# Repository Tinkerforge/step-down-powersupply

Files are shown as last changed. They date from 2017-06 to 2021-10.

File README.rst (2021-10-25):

Step-Down Power Supply
======================

This repository contains the hardware design files for the Step-Down
Power Supply.

Repository Content
------------------

hardware/:
 * Contains kicad project files and additionally schematics as pdf

Hardware
--------

The hardware is designed with the open source EDA Suite KiCad
(http://www.kicad.org). Before you are able to open the files,
you have to install the Tinkerforge kicad-libraries
(https://github.com/Tinkerforge/kicad-libraries). You can either clone
them directly in hardware/ or clone them in a separate folder and
symlink them into hardware/
(ln -s kicad_path/kicad-libraries project_path/hardware). After that you
can open the .pro file in hardware/ with kicad and from there view and
modify the schematics and the PCB layout.

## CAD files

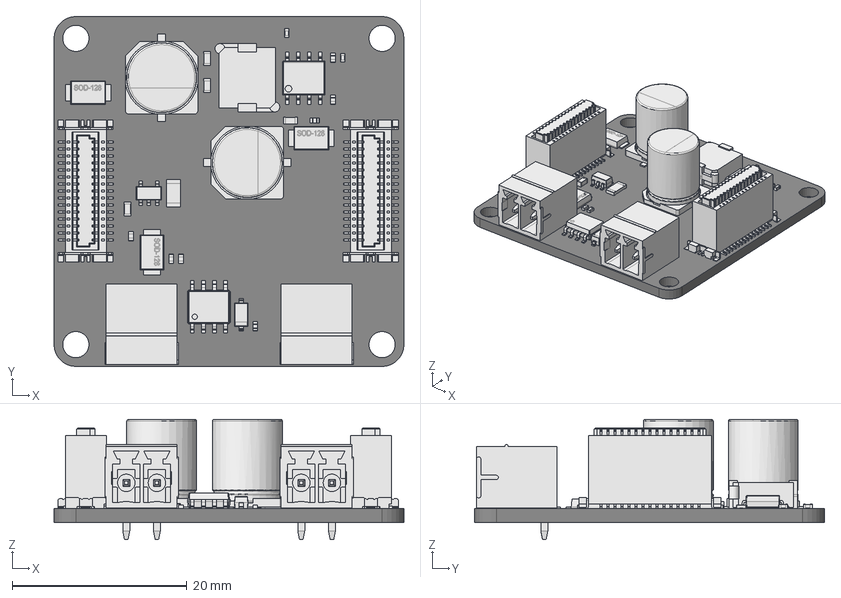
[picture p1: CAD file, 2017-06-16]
hardware/step-down.FCStd
40.0 x 40.0 x 13.8 mm
Pcb
ASSEMBLY_
C_0603_
C_0402_
C_0402_001
C_0603_001
C_0603_002
ASSEMBLY_001
SOD-123_
SOD-128_
SOD-128_001
SOD-128_002
C_0603_003
88021-12XX_
88021-12XX_001
2er_Phoenix_Buchse_Schwarz_
2er_Phoenix_Buchse_Grün_
soic_8_39x49_p127_
R_0402_
R_0402_001
R_0402_002
R_1206_
R_0402_003
R_0402_004
R_0402_005
R_0402_006
SOT-23-5_
SO-8_

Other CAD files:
hardware/V1.3/step_down.FCStd

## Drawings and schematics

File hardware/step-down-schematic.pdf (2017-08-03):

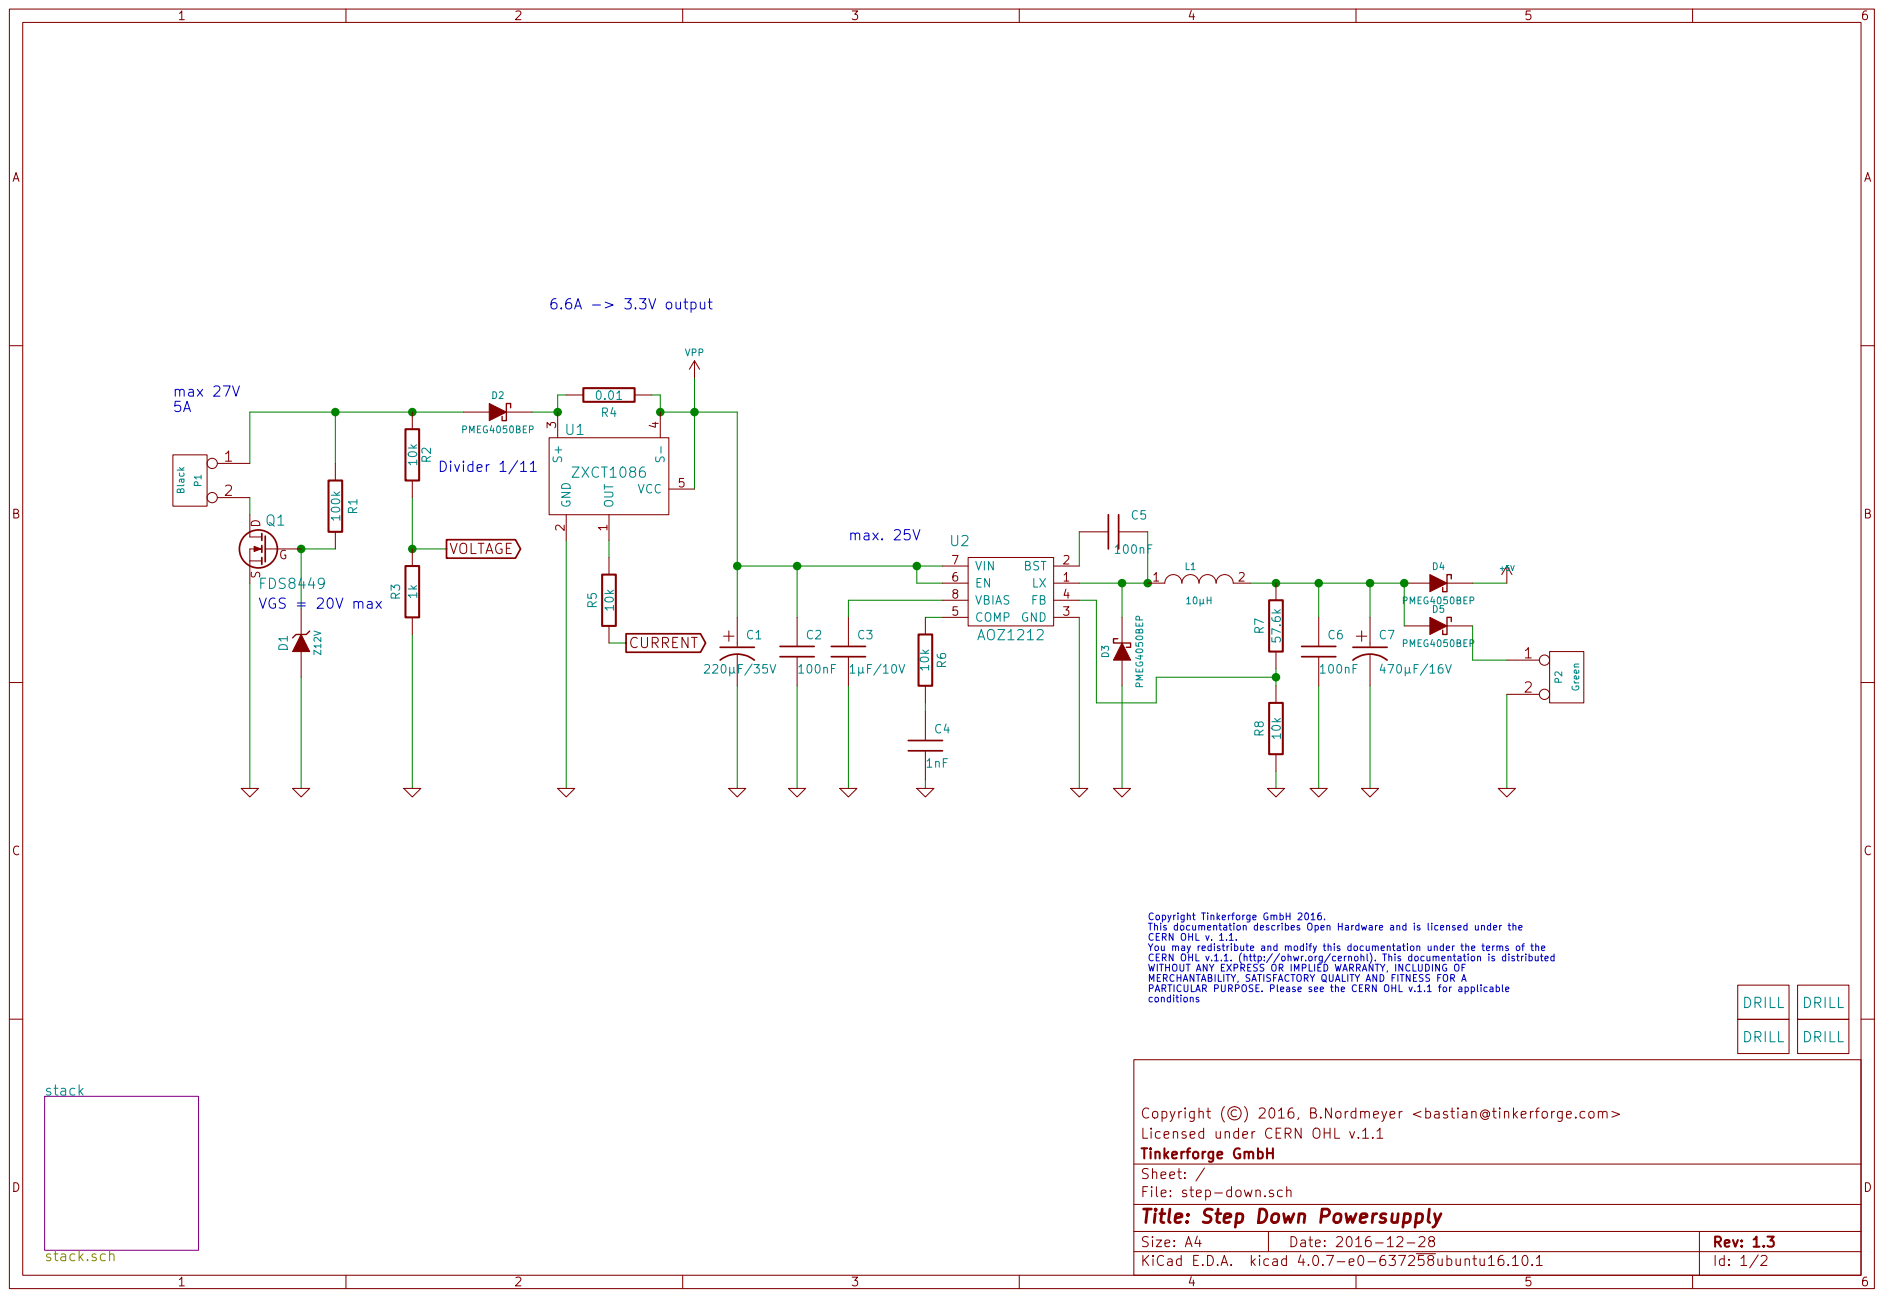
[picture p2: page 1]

PARTICULAR PURPOSE. Please see the CERN OHL v.1.1 for applicable
conditions

Licensed under CERN OHL v.1.1 Copyright (©) 2016, B.Nordmeyer <bastian@tinkerforge.com>

File: step-down.sch Sheet: / Tinkerforge GmbH

Id: 1/2 Title: Step Down Powersupply

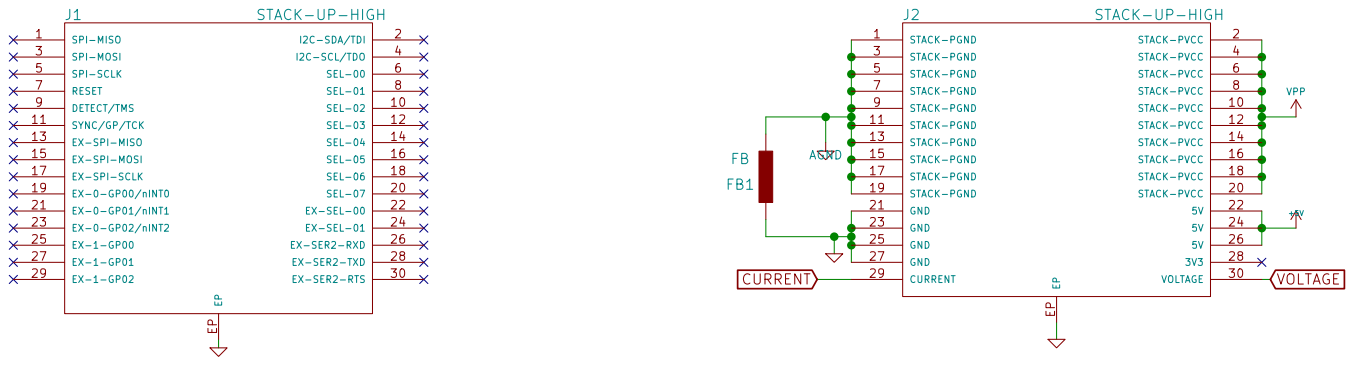
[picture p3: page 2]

Licensed under CERN OHL v.1.1 Copyright (©) 2016, B.Nordmeyer <bastian@tinkerforge.com> FB1 FB

File: stack.sch Sheet: /stack/ Tinkerforge GmbH

Id: 2/2 Title: Step Down Powersupply

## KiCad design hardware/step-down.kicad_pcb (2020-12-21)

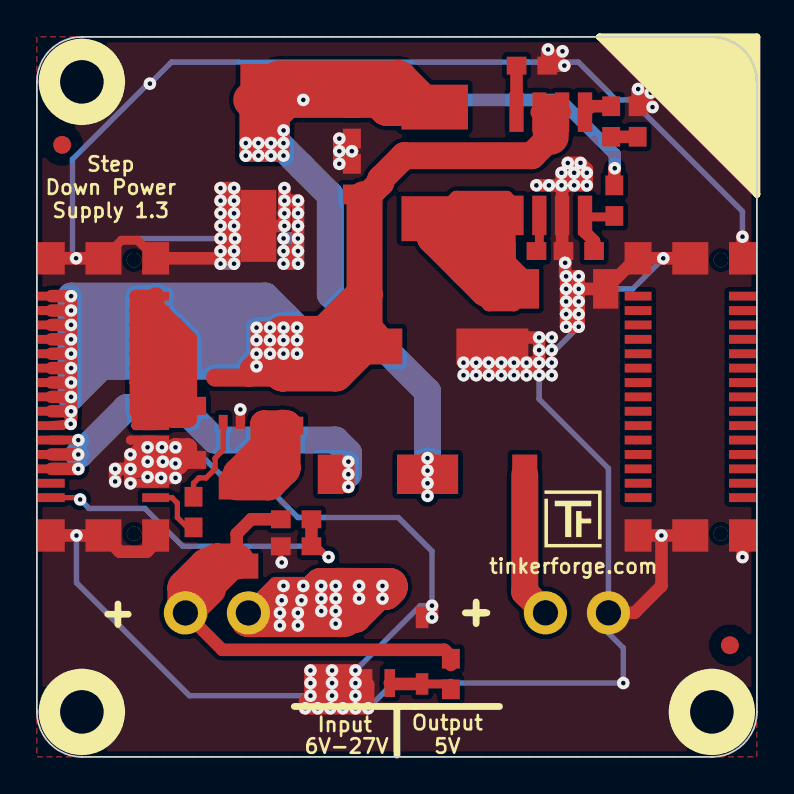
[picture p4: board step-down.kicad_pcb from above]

Board: 2 copper layers, 40.0 x 40.0 mm, 38 parts (0 on the bottom side), 19 nets.

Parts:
C1: 220µF/35V; ELKO_83
C2, C5, C6: 100nF; C0603E
C3: 1µF/10V; C0603E
C4: 1nF; C0603E
C7: 470µF/16V; ELKO_83
D1: Z12V; SOD-123
D2, D3, D4, D5: PMEG4050BEP; SOD-128
FB1: FB; R1206
Fiducial_Mark: VAL**; Fiducial_Mark
Fiducial_Mark#2: VAL**; Fiducial_Mark
J1, J2: STACK-UP-HIGH; BTB08-ACS-TOP
L1: 10µH; SRP7030
P1: Black; OQ_2P
P2: Green; OQ_2P
Q1: FDS8449; SOIC-8-MOSFET
R1: 100k; R0603E
R2, R5: 10k; R0603E
R3: 1k; R0603E
R4: 0.01; R1206
R6, R8: 10k; C0603E
R7: 57.6k; C0603E
Ref**: Val**
U1: ZXCT1086; SOT23-5
U2: AOZ1212; SO-8
U3, U4, U5, U6: DRILL; DRILL_NP
VAL: WEEE_7mm
VAL#2: CE_5mm

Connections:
+5V: D4.2, J2.22, J2.24, J2.26
AGND: FB1.2, J2.1, J2.3, J2.5, J2.7, J2.9, J2.11, J2.13, J2.15, J2.17, J2.19
CURRENT: J2.29, R5.2
GND: C1.2, C2.2, C3.2, C4.2, C6.2, C7.2, D1.1, D3.1, FB1.1, J1.EP, J2.21, J2.23, J2.25, J2.27, J2.EP, P2.2, Q1.S, R3.2, R8.2, U1.2, U2.3
unnamed: C3.1, U2.8
unnamed: C4.1, R6.1
unnamed: C5.1, D3.2, L1.1, U2.1
unnamed: C5.2, U2.2
unnamed: C6.1, C7.1, D4.1, D5.1, L1.2, R7.1
unnamed: D1.2, Q1.G, R1.2
unnamed: D2.1, P1.1, R1.1, R2.1
unnamed: D2.2, R4.2, U1.3
unnamed: D5.2, P2.1
unnamed: P1.2, Q1.D
unnamed: R5.1, U1.1
unnamed: R6.2, U2.5
unnamed: R7.2, R8.1, U2.4
VOLTAGE: J2.30, R2.2, R3.1
VPP: C1.1, C2.1, J2.2, J2.4, J2.6, J2.8, J2.10, J2.12, J2.14, J2.16, J2.18, J2.20, R4.1, U1.4, U1.5, U2.6, U2.7

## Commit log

2013-12-02 add hardware files of version 1.2
    [stack.sch, step-down.brd, step-down.kicad_pcb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]
2013-12-02 schematic in color fix input voltage hint
    [stack.sch, step-down.sch]
2015-05-07 start new prototype of step down power supply with filtered inputs, fuse and diode protected output
    [stack.sch, step-down.kicad_pcb, step-down.sch]
2015-05-07 change 0402 footprints to 0603
    [stack.sch, step-down.sch]
2015-05-18 updated version of new prototype, change current sensor, add filtering, not finished
    [stack.sch, step-down.kicad_pcb, step-down.sch]
2015-05-19 next routing test, vpp seems to be not routable
    [stack.sch, step-down.kicad_pcb, step-down.sch]
2015-05-19 routing finished
    [stack.sch, step-down.kicad_pcb, step-down.sch]
2016-12-28 change version 1.3, remove filters
    [stack.sch, step-down.kicad_pcb, step-down.sch]
2016-12-28 again drc check executed, project settings changed
    [step-down.kicad_pcb]
2017-01-12 update pcb
    [step-down.kicad_pcb]
2017-05-22 change components to new standard components, oder version
    [stack.sch, step-down.kicad_pcb, step-down.sch]
2017-06-02 Add 3d information (tbc)
    [step-down.kicad_pcb]
2017-06-09 fix fab text positions
    [step-down.kicad_pcb]
2017-06-09 Add missing 3d information
    [step-down.kicad_pcb]
2017-06-09 Add 3d model (*.step and *.FCStd)
    [step_down.FCStd]
2017-06-16 Fix MOSFET_N to MOSFET_N_CH
    [step-down.sch]
2017-06-16 Add 3d information to components (tbc)
    [stack.sch, step-down.sch]
2017-06-23 Rename *.FCStd file
    [step-down.FCStd]
2017-08-03 add new version of step down power supply
    [stack.sch, step-down.kicad_pcb, step-down.sch]
2020-12-21 fix 3d modell
    [step-down.kicad_pcb]
2021-10-25 Update KiCad link
    https://www.kicad.org/blog/2021/10/Avoid-links-to-former-kicad-domain/

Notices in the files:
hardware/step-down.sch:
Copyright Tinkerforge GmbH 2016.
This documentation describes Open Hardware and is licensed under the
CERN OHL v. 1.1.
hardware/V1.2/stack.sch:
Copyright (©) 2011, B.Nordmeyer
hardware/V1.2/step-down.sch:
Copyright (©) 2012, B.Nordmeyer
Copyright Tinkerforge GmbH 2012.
